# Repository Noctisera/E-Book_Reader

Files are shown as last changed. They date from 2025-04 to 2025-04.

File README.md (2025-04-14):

# OpenBook Reader

## 📘 Introduction  
**OpenBook Reader** is an open-source hardware project focused on delivering a practical, low-cost e-book device. Its primary aim is to build the physical design assets—such as schematics, board layouts, and casing models—needed for manufacturing the device according to system-level specs.

This initiative includes:
- Circuit design and layout.
- PCB preparation for fabrication.
- CAD models for enclosure and hardware integration.

---

## 🔧 Project Contents

This repository contains everything needed to bring the device to life, from electronics to mechanical files. Key folders include:

- **Electronics Design**
  - Circuit schematics  
  - Board layout data  
- **Fabrication Files**
  - Manufacturing exports (e.g., Gerbers)  
  - Assembly references (e.g., BOM, placement files)  
- **CAD Assets**
  - Mechanical parts in 3D format (STEP, Fusion360)  
- **Miscellaneous**
  - Licensing information  
  - Documentation  

---

## 📦 Components Summary

### Block Diagram
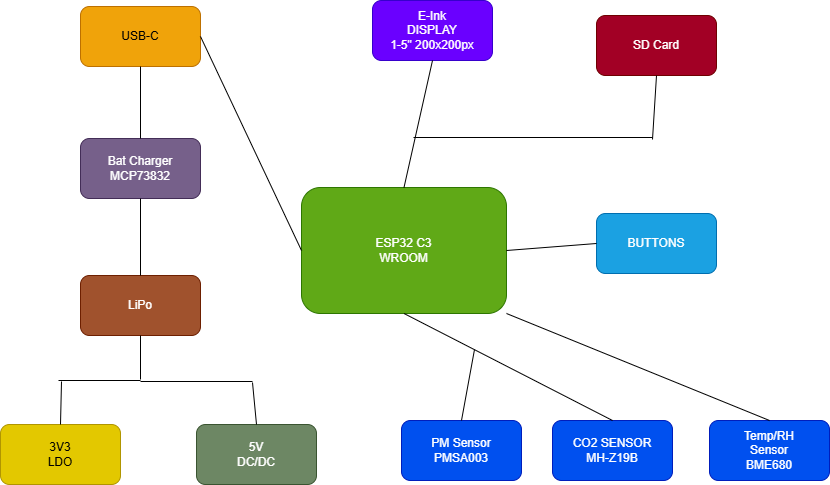
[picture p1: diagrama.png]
E-Book Reader Diagram


Below is a selection of the main components used in the hardware design. For each, you’ll find supplier and datasheet links for reference.

## Bill of Materials (BOM)

| Component | Link | Datasheet |
| :--- | :--- | :--- |
| ESP32-C6 WROOM-1-N8 | [SnapMagic](https://www.snapeda.com/parts/ESP32-C6-WROOM-1-N8/Espressif+Systems/view-part/?ref=eda) | [Datasheet](https://www.snapeda.com/parts/ESP32-C6-WROOM-1-N8/Espressif%20Systems/datasheet/) |
| ESP32C6 Varistor 1812 | [Mouser](https://ro.mouser.com/ProductDetail/EPCOS-TDK/B72520T0350K062?qs=dEfas%2FXlABIszF52uu7vrg%3D%3D) | [Datasheet](https://www.tdk-electronics.tdk.com/inf/75/db/CTVS_14/Surge_protection_series.pdf) |
| ESP32 WROVER 0805 Capacitor | [Mouser](https://ro.mouser.com/ProductDetail/KYOCERA-AVX/SD0805S020S1R0?qs=jCA%252BPfw4LHbpkAoSnwrdjw%3D%3D) | [Datasheet](https://ro.mouser.com/datasheet/2/40/schottky-3165252.pdf) |
| ESP32 WROVER BME680 Sensor | [SnapMagic](https://www.snapeda.com/parts/BME680/Bosch/view-part/?welcome=home) | [Datasheet](https://www.snapeda.com/parts/BME680/Bosch%20Sensortec/datasheet/) |
| ESP32 WROVER MCP73831 Power Management | [Mouser](https://eu.mouser.com/ProductDetail/Microchip-Technology/MCP73831T-2ACI-OT?qs=yUQqVecv4qvbBQBGbHx0Mw%3D%3D) | [Datasheet](https://eu.mouser.com/datasheet/2/268/MCP73831_Family_Data_Sheet_DS20001984H-3441711.pdf) |
| ESP32 WROVER P-Channel MOSFET | [Component Search Engine](https://componentsearchengine.com/part-view/DMG2305UX-7/Diodes%20Incorporated) | [Datasheet](https://www.diodes.com//assets/Datasheets/DMG2305UX.pdf) |
| LED Chip 0603 | [SnapMagic](https://www.snapeda.com/parts/KP-1608SURCK/Kingbright/view-part/?ref=search&t=LED%200603) | [Datasheet](https://www.snapeda.com/parts/KP-1608SURCK/Kingbright/datasheet/) |
| SJ | [GrabCad](https://grabcad.com/library/solder-jumpers-1) | [Datasheet](https://www.youtube.com/watch?v=dQw4w9WgXcQ) |
| LTSPICE Resistor 0402 | [Component Search Engine](https://componentsearchengine.com/part-view/R0402%201%25%20100%20K%20(RC0402FR-07100KL)/YAGEO) | [Datasheet](https://www.yageo.com/upload/media/product/products/datasheet/rchip/PYu-RC_Group_51_RoHS_L_12.pdf) |
| RCL CPOL 3528 | [SnapMagic](https://www.snapeda.com/parts/TAJB475K025RNJ/AVX/view-part/?ref=dk&t=capacitor%203528&con_ref=None) | [Datasheet](https://s3.amazonaws.com/snapeda/datasheet/TAJB475K025RNJ_AVX.pdf) |
| 112A-TAAR-R03 | [Comet](https://store.comet.srl.ro/Catalogue/Product/43497/) | [Datasheet](https://store.comet.bg/download-file.php?id=27596) |
| Capacitor 0402 | [Component Search Engine](https://componentsearchengine.com/part-view/CC0402MRX5R5BB106/YAGEO) | [Datasheet](https://componentsearchengine.com/Datasheets/2/CC0402MRX5R5BB106.pdf) |
| 744043680 IND | [Mouser](https://eu.mouser.com/ProductDetail/Wurth-Elektronik/744043680?qs=PGXP4M47uW6VkZq%252BkzjrHA%3D%3D) | [Datasheet](https://www.we-online.com/components/products/datasheet/744043680.pdf) |
| BD5229G-TR | [Component Search Engine](https://componentsearchengine.com/part-view/BD5229G-TR/ROHM%20Semiconductor) | [Datasheet](https://datasheet.datasheetarchive.com/originals/distributors/Datasheets_SAMA/f2b9741ef86007909f138d561a359946.pdf) |
| Custom Button | [Panasonic](https://industry.panasonic.com/global/en/products/control/switch/light-touch/number/evqpuj02k) | [Datasheet](https://industry.panasonic.com/global/en/downloads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) |
| CPH3225A | [SnapMagic](https://www.snapeda.com/parts/CPH3225A/Seiko+Instruments/view-part/?ref=eda) | [Datasheet](https://www.snapeda.com/parts/CPH3225A/Seiko%20Instruments/datasheet/) |
| DS3231SN RTC | [SnapMagic](https://www.snapeda.com/parts/DS3231SN%23/Analog+Devices/view-part/?ref=eda) | [Datasheet](https://www.snapeda.com/parts/DS3231SN%23/Analog%20Devices/datasheet/) |
| FH34SRJ-24S-0.5SH Connector | [Component Search Engine](https://componentsearchengine.com/part-view/FH34SRJ-24S-0.5SH(99)/Hirose) | [Datasheet](https://www.hirose.com/en/product/document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) |
| MAX17048G+T10 Battery Fuel Gauge | [SnapMagic](https://www.snapeda.com/parts/MAX17048G+T10/Analog+Devices/view-part/?ref=eda) | [Datasheet](https://www.snapeda.com/parts/MAX17048G+T10/Analog%20Devices/datasheet/) |
| MBR0530 Schottky Diode | [SnapMagic](https://www.snapeda.com/parts/MBR0530/Onsemi/view-part/?ref=eda) | [Datasheet](https://www.snapeda.com/parts/MBR0530/ON%20Semiconductor/datasheet/) |
| PGB1010603MR Inductor | [SnapMagic](https://www.snapeda.com/parts/PGB1010603MR/Littelfuse/view-part/?ref=eda) | [Datasheet](https://www.snapeda.com/parts/PGB1010603MR/Littelfuse%20Inc./datasheet/) |
| QWIIC Connector | [Mouser](https://eu.mouser.com/ProductDetail/Adafruit/4208?qs=PzGy0jfpSMtbScLbr0L5dw%3D%3D) | [Datasheet](https://www.youtube.com/watch?v=dQw4w9WgXcQ) |
| USB4110-GF-A USB Hub | [Component Search Engine](https://componentsearchengine.com/part-view/USB4110-GF-A/GCT%20(GLOBAL%20CONNECTOR%20TECHNOLOGY)) | [Datasheet](https://gct.co/files/drawings/usb4110.pdf) |
| SI1308EDL-T1-GE3 MOSFET | [SnapMagic](https://www.snapeda.com/parts/SI1308EDL-T1-GE3/Vishay+Siliconix/view-part/?ref=eda) | [Datasheet](https://www.youtube.com/watch?v=dQw4w9WgXcQ) |
| TPTP20R | [Comet](https://easyeda.com/component/7524403feb2642ac9f9f26dfb93ceacf) | [Datasheet](https://easyeda.com/component/7524403feb2642ac9f9f26dfb93ceacf) |
| USBLC6-2SC6Y USB Surge Protection | [SnapMagic](https://www.snapeda.com/parts/USBLC6-2SC6Y/STMicroelectronics/view-part/?ref=eda) | [Datasheet](https://www.snapeda.com/parts/USBLC6-2SC6Y/STMicroelectronics/datasheet/) |
| W25Q512JVEIQ Flash Memory | [SnapMagic](https://www.snapeda.com/parts/W25Q512JVEIQ/Winbond+Electronics/view-part/?ref=eda) | [Datasheet](https://www.snapeda.com/parts/W25Q512JVEIQ/Winbond%20Electronics/datasheet/) |
| XC6220A331MR-G Voltage Regulator | [Component Search Engine](https://componentsearchengine.com/part-view/XC6220A331MR-G/Torex) | [Datasheet](https://product.torexsemi.com/system/files/series/xc6220.pdf) |

---

## 🧠 Key Modules and Functionality

### 🟡 Power System  
- **Battery:** Rechargeable Li-Po providing 3.7V, 1800mAh capacity.  
- **Charger:** Manages safe charging through USB-C.  
- **Regulation:** LDOs provide clean power to different system sections.

### 🔲 Display Unit  
- **Type:** 7.5-inch e-paper screen (black & white).  
- **Comms:** SPI-based, ultra-low-power refresh.

### 🎛 Microcontroller  
- **Model:** ESP32-C6  
- **Role:** Central processor managing all I/O, display, memory, and sensors.  
- **Connectivity:** Offers Wi-Fi and Bluetooth for syncing or updates.

### 🌦 Environmental Sensor  
- **Chip:** BME688  
- **Function:** Captures environmental data (temp, pressure, humidity, gas).

### 🕒 Real-Time Clock  
- **RTC:** DS3231  
- **Use Case:** Keeps time even without power—great for tracking usage.

### 💾 Storage  
- **Flash Memory:** For storing firmware and runtime data.  
- **SD Card Support:** Optional external storage for large file handling (e.g. e-books).

### 🧩 Expandability  
- **Connectors:** I2C/SPI breakout headers support add-on modules.  
- **Test Points:** Available for programming, debugging, and diagnostics.

---

## 🔌 Interfaces & I/O

| Interface | Purpose |
|---|---|
| **SPI**  | Display, SD Card, Flash Memory |
| **I2C**  | Sensor, RTC |
| **USB-C**| Charging & data |
| **GPIO** | Button inputs, status indicators |

---

## 📃 License  
This project is released under the MIT License—feel free to use, remix, and contribute.

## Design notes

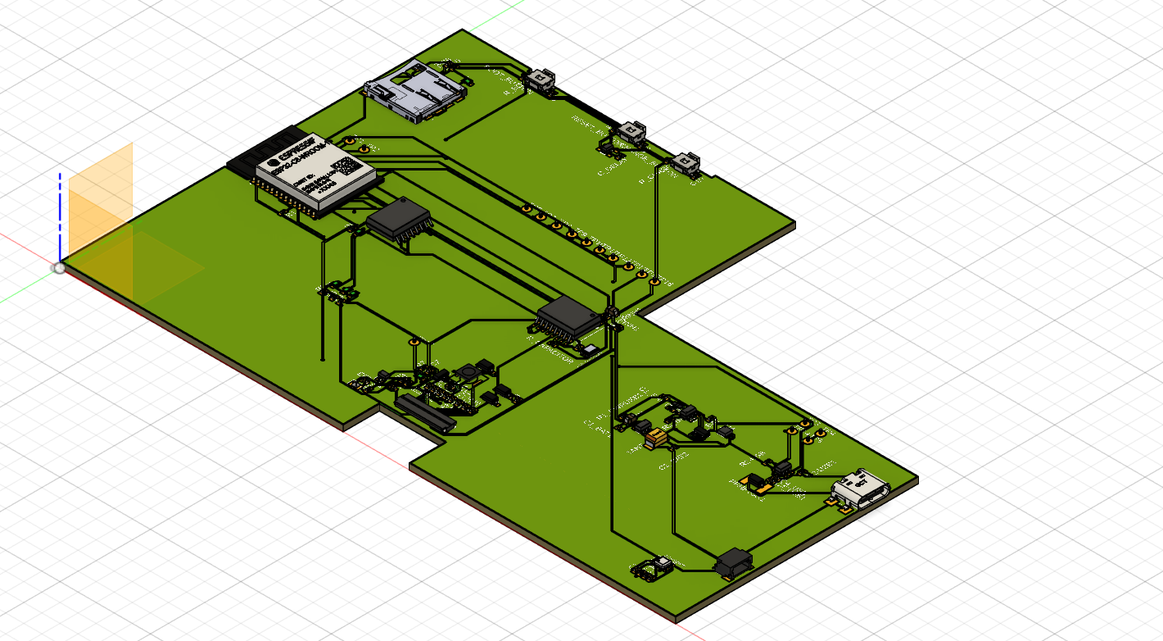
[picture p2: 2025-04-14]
Images/3D_PCB.png

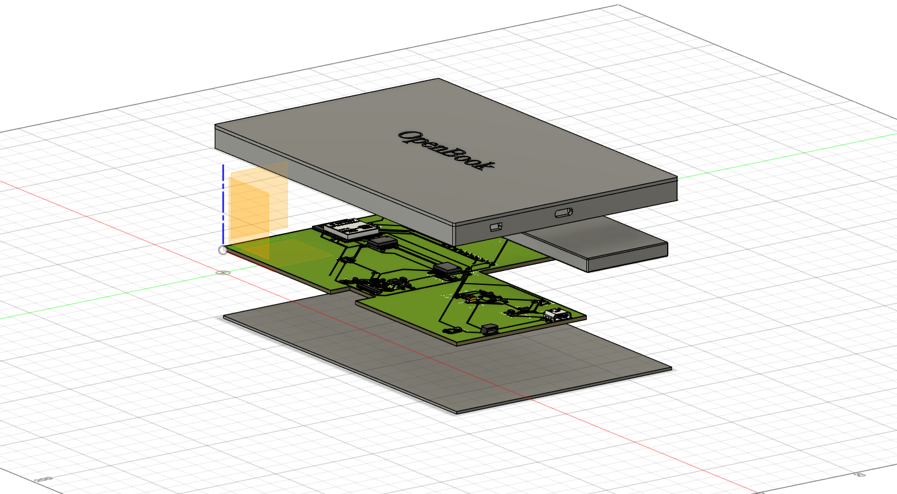
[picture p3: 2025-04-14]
Images/Layered View.png

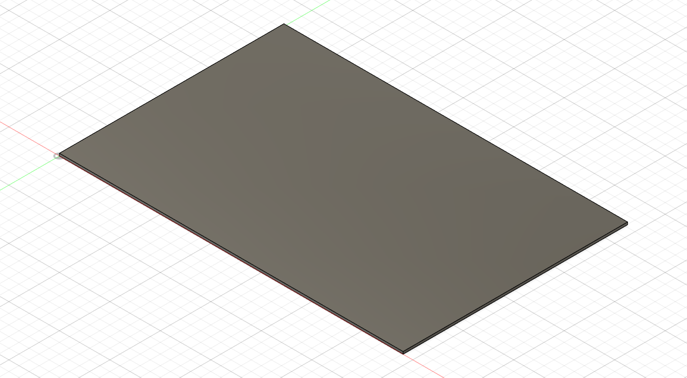
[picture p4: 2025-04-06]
Images/Display v1.png

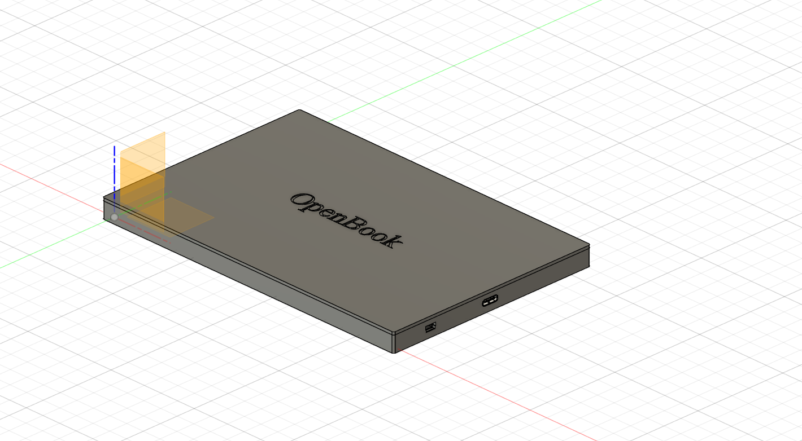
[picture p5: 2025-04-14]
Images/Whole E-Book.png

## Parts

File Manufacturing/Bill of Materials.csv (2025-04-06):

Qty | Value | Device | Package | Parts | Description | ARROW_PART_NUMBER | ARROW_PRICE-STOCK | AVAILABILITY | CENTROID_NOT_SPECIFIED | CHECK_PRICES | COPYRIGHT | DATASHEET | DESCRIPTION | DIGIKEY_DESCRIPTION | DIGIKEY_PART_NUMBER | HEIGHT | LEAD_FREE | MANUFACTURER_NAME | MANUFACTURER_PART_NUMBER | MF | MFR_NAME | MOUSER_PART_NUMBER | MOUSER_PRICE-STOCK | MOUSER_TESTING_PART_NUMBER | MOUSER_TESTING_PRICE-STOCK | MP | MPN | PACKAGE | POPULARITY | PREFIX | PRICE | PROD_ID | PURCHASE-URL | ROHS | SNAPEDA_LINK | SPICEMODEL | SPICEPREFIX | TEMPERATURE_RANGE_HIGH | TEMPERATURE_RANGE_LOW | TP_SIGNAL_NAME | VALUE
1 |  | ADAFRUIT_LEDCHIP-LED0603 | ADAFRUIT_CHIP-LED0603 | CHG_LED | LED
1 |  | SJ | SJ | SJ1 | SMD solder JUMPER |  |  |  |  |  |  |  |  |  |  |  |  |  |  |  |  |  |  |  |  |  |  |  | 3
1 | 0.47 | ESP32_WROVER_EAGLE-LTSPICE_RR0402 | ESP32_WROVER_EAGLE-LTSPICE_R0402 | R3 | RESISTOR, European symbol |  |  |  |  |  |  |  |  |  |  |  |  |  |  |  |  |  |  |  |  |  |  |  |  |  |  |  |  |  |  | NONE | R
1 | 100K | ESP32_WROVER_EAGLE-LTSPICE_RR0402 | ESP32_WROVER_EAGLE-LTSPICE_R0402 | R1_PWRUSB1 | RESISTOR, European symbol |  |  |  |  |  |  |  |  |  |  |  |  |  |  |  |  |  |  |  |  |  |  |  |  |  |  |  |  |  |  | NONE | R
8 | 100nF | EAGLE-LTSPICE_CC0402 | EAGLE-LTSPICE_C0402 | C1, C2, C4_USB1, C6, C8, C9, C10, C_DELAY | CAPACITOR, European symbol |  |  |  |  |  |  |  |  |  |  |  |  |  |  |  |  |  |  |  |  |  |  |  |  |  |  |  |  |  |  | NONE | C
1 | 100uF | RCL_CPOL-EUCT3528 | RCL_CT3528 | TANT | POLARIZED CAPACITOR, European symbol |  |  |  |  |  |  |  |  |  |  |  |  |  |  |  |  |  |  |  |  |  |  |  | 0 |  |  |  |  |  |  |  | C
17 | 10K | ESP32_WROVER_EAGLE-LTSPICE_RR0402 | ESP32_WROVER_EAGLE-LTSPICE_R0402 | R1, R1_PINH, R1_PINH1, R2-USB1, R2_PINH, R2_PINH1, R4, R5, R6, R7, R8, R9, R10, R_BOOT, R_CHANGE, R_CL1, R_RESET | RESISTOR, European symbol |  |  |  |  |  |  |  |  |  |  |  |  |  |  |  |  |  |  |  |  |  |  |  |  |  |  |  |  |  |  | NONE | R
1 | 10uF | EAGLE-LTSPICE_CC0402 | EAGLE-LTSPICE_C0402 | C7 | CAPACITOR, European symbol |  |  |  |  |  |  |  |  |  |  |  |  |  |  |  |  |  |  |  |  |  |  |  |  |  |  |  |  |  |  | NONE | C
1 | 112A-TAAR-R03_ATTEND | 112A-TAAR-R03_ATTEND | 112ATAARR03ATTEND | J4 | Micro SD Card Socket, Push-Push Type, Top Mount, SMT, H=1.83mm, 10u |  |  |  |  |  |  |  | Micro SD Card Socket | Push-Push Type | Top Mount | SMT | H=1.83mm | 10u |  |  | 1.9mm |  | ATTEND | 112A-TAAR-R03 ATTEND
1 | 15 | ESP32_WROVER_EAGLE-LTSPICE_RR0402 | ESP32_WROVER_EAGLE-LTSPICE_R0402 | R_CAPACITOR | RESISTOR, European symbol |  |  |  |  |  |  |  |  |  |  |  |  |  |  |  |  |  |  |  |  |  |  |  |  |  |  |  |  |  |  | NONE | R
1 | 1uF | EAGLE-LTSPICE_CC0402 | EAGLE-LTSPICE_C0402 | C5 | CAPACITOR, European symbol |  |  |  |  |  |  |  |  |  |  |  |  |  |  |  |  |  |  |  |  |  |  |  |  |  |  |  |  |  |  | NONE | C
10 | 1uF/50V | EAGLE-LTSPICE_CC0402 | EAGLE-LTSPICE_C0402 | EFD_C1, EFD_C2, EFD_C5, EFD_C6, EFD_C7, EPD_C8, EPD_C9, EPD_C10, EPD_C11, EPD_C12 | CAPACITOR, European symbol |  |  |  |  |  |  |  |  |  |  |  |  |  |  |  |  |  |  |  |  |  |  |  |  |  |  |  |  |  |  | NONE | C
1 | 2.2 | ESP32_WROVER_EAGLE-LTSPICE_RR0402 | ESP32_WROVER_EAGLE-LTSPICE_R0402 | R2 | RESISTOR, European symbol |  |  |  |  |  |  |  |  |  |  |  |  |  |  |  |  |  |  |  |  |  |  |  |  |  |  |  |  |  |  | NONE | R
1 | 200 | ESP32_WROVER_EAGLE-LTSPICE_RR0402 | ESP32_WROVER_EAGLE-LTSPICE_R0402 | R1_BAT | RESISTOR, European symbol |  |  |  |  |  |  |  |  |  |  |  |  |  |  |  |  |  |  |  |  |  |  |  |  |  |  |  |  |  |  | NONE | R
2 | 20V/4.2A/52m?/1.4W | ESP32_WROVER_SPARKFUN-DISCRETESEMI_MOSFET_PCH-DMG2305UX-7 | ESP32_WROVER_SPARKFUN-DISCRETESEMI_SOT23-3 | Q1, Q2 | P-channel MOSFETs |  |  |  |  |  |  |  |  |  |  |  |  |  |  |  |  |  |  |  |  |  |  |  |  |  |  | TRAN-14388 |  |  |  |  |  |  |  |  | 20V/4.2A/52m?/1.4W
1 | 2K | ESP32_WROVER_EAGLE-LTSPICE_RR0402 | ESP32_WROVER_EAGLE-LTSPICE_R0402 | R2_BAT | RESISTOR, European symbol |  |  |  |  |  |  |  |  |  |  |  |  |  |  |  |  |  |  |  |  |  |  |  |  |  |  |  |  |  |  | NONE | R
5 | 4.7uF | EAGLE-LTSPICE_CC0402 | EAGLE-LTSPICE_C0402 | C1_BAT, C1_BAT1, C1_BAT2, C2_BAT, C4_USB | CAPACITOR, European symbol |  |  |  |  |  |  |  |  |  |  |  |  |  |  |  |  |  |  |  |  |  |  |  |  |  |  |  |  |  |  | NONE | C
1 | 4.7uF/25V | EAGLE-LTSPICE_CC0402 | EAGLE-LTSPICE_C0402 | C4 | CAPACITOR, European symbol |  |  |  |  |  |  |  |  |  |  |  |  |  |  |  |  |  |  |  |  |  |  |  |  |  |  |  |  |  |  | NONE | C
1 | 5k1 | ESP32_WROVER_EAGLE-LTSPICE_RR0402 | ESP32_WROVER_EAGLE-LTSPICE_R0402 | R2-USB | RESISTOR, European symbol |  |  |  |  |  |  |  |  |  |  |  |  |  |  |  |  |  |  |  |  |  |  |  |  |  |  |  |  |  |  | NONE | R
1 | 744043680IND_4828-WE-TPC_WRE | 744043680IND_4828-WE-TPC_WRE | IND_4828-WE-TPC_WRE | L1 |  |  |  |  |  |  | Copyright (C) 2024 Ultra Librarian. All rights reserved. |  |  |  |  |  |  |  | 744043680 |  | Wurth Electronics
1 | BD5229G-TR | BD5229G-TR | SOT95P280X125-5N | IC1 | Voltage Detector with Adjustable Delay Time: CMOS processes are utilized to develop high precision, low current consumption CMOS reset ICs that allow arbitrary setting of the delay time. The extensive lineup includes both Nch Open Drain and CMOS output types in a wide range of detection voltages (from 2.3V to 6.0V, in 0.1V steps), enabling selection of the ideal solution based on customer requirements. In addition, the entire series is of course both lead-free and RoHS-compliant. |  |  |  |  |  |  |  | Voltage Detector with Adjustable Delay Time: CMOS processes are utilized to develop high precision | low current consumption CMOS reset ICs that allow arbitrary setting of the delay time. The extensive lineup includes both Nch Open Drain and CMOS output types in a wide range of detection voltages (from 2.3V to 6.0V | in 0.1V steps) | enabling selection of the ideal solution based on customer requirements. In addition | the entire series is of course both lead-free and RoHS-compliant. |  |  | 1.25mm |  | ROHM Semiconductor | BD5229G-TR |  |  | 755-BD5229G-TR | https://www.mouser.co.uk/ProductDetail/ROHM-Semiconductor/BD5229G-TR?qs=4kLU8WoGk0vvnhrrYwdszw%3D%3D
3 | BUTTON_CUSYOMV1 | BUTTON_CUSYOMV1 | MYBUTTON | BOOT_BUTTON, CHANGE_BUTTON, RESET_BUTTON
1 | CPH3225A | CPH3225A | CAPCP3225X100N | C10_SUPERCAP | Cap 0.011F 3.3V 1210 Flat Check availability |  |  | Not in stock |  | https://www.snapeda.com/parts/CPH3225A/Seiko+Instruments/view-part/?ref=eda |  |  | 11 mF (EDLC) Supercapacitor 3.3 V 1210 (3225 Metric) - - |  |  |  |  |  |  | Seiko Instruments |  |  |  |  |  | CPH3225A |  | 1210 Seiko |  |  | None |  | https://www.snapeda.com/api/url_track_click_mouser/?unipart_id=562593&manufacturer=Seiko Instruments&part_name=CPH3225A&search_term=None |  | https://www.snapeda.com/parts/CPH3225A/Seiko+Instruments/view-part/?ref=snap
1 | DS3231SN# | DS3231SN# | SOIC127P1032X265-16N | U3 | Real Time Clock Serial 16-Pin SOIC W T/R Check availability |  |  | In Stock |  | https://www.snapeda.com/parts/DS3231SN%23/Analog+Devices/view-part/?ref=eda |  |  | Extremely Accurate I2C-Integrated RTC/TCXO/Crystal |  |  |  |  |  |  | Analog Devices |  |  |  |  |  | DS3231SN# |  | SOIC-16 Maxim |  |  | None |  | https://www.snapeda.com/api/url_track_click_mouser/?unipart_id=99048&manufacturer=Analog Devices&part_name=DS3231SN#&search_term=None |  | https://www.snapeda.com/parts/DS3231SN%23/Analog+Devices/view-part/?ref=snap
1 | ESP32-C6-WROOM-1-N8 | ESP32-C6-WROOM-1-N8 | XCVR_ESP32-C6-WROOM-1-N8 | U2 | Check availability |  |  | In Stock |  | https://www.snapeda.com/parts/ESP32-C6-WROOM-1-N8/Espressif+Systems/view-part/?ref=eda |  |  | Multiprotocol Modules ESP32-C6 module | Wi-Fi 6 in 2.4 GHz band | Bluetooth 5 | Zigbee 3.0 and Thread. ESP34-WROOM Compatible - ENGINEERING SAMPLE |  |  |  |  |  |  | Espressif Systems |  |  |  |  |  | ESP32-C6-WROOM-1-N8 |  | None |  |  | None |  |  |  | https://www.snapeda.com/parts/ESP32-C6-WROOM-1-N8/Espressif+Systems/view-part/?ref=snap
1 | ESP32C6_VARISTORCN1812 | ESP32C6_VARISTORCN1812 | ESP32C6_VARISTOR_CT/CN1812 | PFMF.050.1 | VARISTOR |  |  |  |  |  |  |  |  |  |  |  |  |  |  |  |  |  |  |  |  |  |  |  | 0
2 | ESP32_WROVER_AVX---SD0805S020S1R0_AVX_SD0805S020S1R0_0_0AVX_SD0805S020S1R0_0_0 | ESP32_WROVER_AVX---SD0805S020S1R0_AVX_SD0805S020S1R0_0_0AVX_SD0805S020S1R0_0_0 | ESP32_WROVER_AVX---SD0805S020S1R0_AVX_SD0805S020S1R0_0 | D2, D7 | Schottky Barrier Rectifier Diode |  |  |  | No |  |  | http://datasheets.avx.com/schottky.pdf |  | DIODE SCHOTTKY 20V 1A 0805 | 478-7800-1-ND |  | yes |  |  | AVX |  | 581-SD0805S020S1R0 |  |  |  |  |  | 0805 (2012 metric) |  | D |  |  |  | yes |  |  |  | +125°C | -55°C
1 | ESP32_WROVER_BME680_BME680 | ESP32_WROVER_BME680_BME680 | ESP32_WROVER_BME680_PSON80P300X300X100-8N | SENSOR2 | Integrated Environmental Unit |  |  | Unavailable |  |  |  |  | Integrated Environmental Unit |  |  |  |  |  |  | Bosch Sensortec |  |  |  |  |  | BME680 |  | LGA-8 Bosch Tools |  |  | None
1 | ESP32_WROVER_SPARKFUN-IC-POWER_MCP73831 | ESP32_WROVER_SPARKFUN-IC-POWER_MCP73831 | ESP32_WROVER_SPARKFUN-IC-POWER_SOT23-5 | MCP73831 | MCP73831T Li-Ion, Li-Pol Controller |  |  |  |  |  |  |  |  |  |  |  |  |  |  |  |  |  |  |  |  |  |  |  |  |  |  | IC-09995
1 | FH34SRJ-24S-0.5SH_99_ | FH34SRJ-24S-0.5SH_99_ | FH34SRJ24S05SH99 | J1 | (0.50mm) Surface Mount, Right Angle |  |  |  |  |  |  |  | 24 Position FFC | FPC Connector Contacts | (0.50mm) Surface Mount | Right Angle |  |  | 1.1mm |  | Hirose | FH34SRJ-24S-0.5SH(99) |  |  | 798-FH34SRJ24S05SH99 | https://www.mouser.co.uk/ProductDetail/Hirose-Connector/FH34SRJ-24S-0.5SH99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
1 | MAX17048G+T10 | MAX17048G+T10 | SON50P200X200X80-9N | U4 | Check availability |  |  | In Stock |  | https://www.snapeda.com/parts/MAX17048G+T10/Analog+Devices/view-part/?ref=eda |  |  | 3µA 1-Cell/2-Cell Fuel Gauge with ModelGauge |  |  |  |  |  |  | Analog Devices |  |  |  |  |  | MAX17048G+T10 |  | TDFN-8 Maxim |  |  | None |  | https://www.snapeda.com/api/url_track_click_mouser/?unipart_id=329239&manufacturer=Analog Devices&part_name=MAX17048G+T10&search_term=None |  | https://www.snapeda.com/parts/MAX17048G+T10/Analog+Devices/view-part/?ref=snap
3 | MBR0530 | MBR0530 | SOD3716X135N | D3, D4, D5 | ON SEMICONDUCTOR - MBR0530 - DIODE, SCHOTTKY, 0.5A, 30V, SOD-123 |  |  | In Stock |  | https://www.snapeda.com/parts/MBR0530/Onsemi/view-part/?ref=eda |  |  | Diode Schottky 30 V 500mA Surface Mount SOD-123 |  |  |  |  |  |  | ON Semiconductor |  |  |  |  |  | MBR0530 |  | SOD-123-2 ON Semiconductor |  |  | None |  | https://www.snapeda.com/api/url_track_click_mouser/?unipart_id=179458&manufacturer=ON Semiconductor&part_name=MBR0530&search_term=None |  | https://www.snapeda.com/parts/MBR0530/Onsemi/view-part/?ref=snap
6 | PGB1010603MR | PGB1010603MR | DIOC1608X36N | D6, D8, D9, D10, D11, D12 | Check availability |  |  | In Stock |  | https://www.snapeda.com/parts/PGB1010603MR/Littelfuse/view-part/?ref=eda |  |  | 150V (Typ) Clamp - Ipp Tvs Diode Surface Mount 0603 (1608 Metric) |  |  |  |  |  |  | Littelfuse Inc. |  |  |  |  |  | PGB1010603MR |  | 0603 Littelfuse Inc. |  |  | None |  | https://www.snapeda.com/api/url_track_click_mouser/?unipart_id=5659453&manufacturer=Littelfuse Inc.&part_name=PGB1010603MR&search_term=None |  | https://www.snapeda.com/parts/PGB1010603MR/Littelfuse/view-part/?ref=snap
1 | QWIIC_RIGHT_ANGLE | QWIIC_CONNECTORJS-1MM | JST04_1MM_RA | J3 | SparkFun I2C Standard Qwiic Connector |  |  |  |  |  |  |  |  |  |  |  |  |  |  |  |  |  |  |  |  |  |  |  |  |  |  | CONN-13694 |  |  |  |  |  |  |  |  | QWIIC_RIGHT_ANGLE
1 | SAMACSYS_PARTS_USB4110-GF-A | SAMACSYS_PARTS_USB4110-GF-A | SAMACSYS_PARTS_USB4110GFA | J2 | CONN USB 2.0 TYPE-C R/A SMT |  |  |  |  |  |  |  | CONN USB 2.0 TYPE-C R/A SMT |  |  | 3.26mm |  | GCT (GLOBAL CONNECTOR TECHNOLOGY) | USB4110-GF-A |  |  | 640-USB4110-GF-A | https://www.mouser.co.uk/ProductDetail/GCT/USB4110-GF-A?qs=KUoIvG%2F9IlYiZvIXQjyJeA%3D%3D
1 | SI1308EDL-T1-GE3 | SI1308EDL-T1-GE3 | SOT65P210X110-3N | Q3 | MOSFET N-Ch 30V 1.5A TrenchFET SC70 Vishay Si1308EDL-T1-GE3 N-channel MOSFET Transistor, 1.5 A, 30 V, 3-Pin SC-70 |  |  | In Stock |  | https://www.snapeda.com/parts/SI1308EDL-T1-GE3/Vishay+Siliconix/view-part/?ref=eda |  |  | Si1308EDL-T1-GE3 N-channel MOSFET Transistor | 1.5 A | 30 V | 3-Pin SC-70 | Siliconix / Vishay SI1308EDL-T1-GE3 |  |  |  |  |  |  | Vishay Siliconix |  |  |  |  |  | SI1308EDL-T1-GE3 |  | SOT-323 Vishay Semiconductor |  |  | None |  | https://www.snapeda.com/api/url_track_click_mouser/?unipart_id=274603&manufacturer=Vishay Siliconix&part_name=SI1308EDL-T1-GE3&search_term=None |  | https://www.snapeda.com/parts/SI1308EDL-T1-GE3/Vishay+Siliconix/view-part/?ref=snap
17 | TPTP20R | TPTP20R | TP20R | TP1, TP2, TP3, TP4, TP5, TP6, TP7, TP8, TP9, TP10, TP11, TP12, TP13, TP14, TP15, TP16, TP17 | Test pad |  |  |  |  |  |  |  |  |  |  |  |  |  |  |  |  |  |  |  |  |  |  |  | 2
1 | USBLC6-2SC6Y | USBLC6-2SC6Y | SOT95P280X145-6N | D1 | Low Cap. ESD Protection Auto SOT-23-6 STMicroelectronics USBLC6-2SC6Y, Dual Uni-Directional TVS Diode Array, 6-Pin SOT-23 |  |  | In Stock |  | https://www.snapeda.com/parts/USBLC6-2SC6Y/STMicroelectronics/view-part/?ref=eda |  |  | 17V Clamp 5A (8/20µs) Ipp Tvs Diode Surface Mount SOT-23-6 |  |  |  |  |  |  | STMicroelectronics |  |  |  |  |  | USBLC6-2SC6Y |  | SOT-23-6 STMicroelectronics |  |  | None |  |  |  | https://www.snapeda.com/parts/USBLC6-2SC6Y/STMicroelectronics/view-part/?ref=snap
1 | W25Q512JVEIQ | W25Q512JVEIQ | SON127P600X800X80-9N | U1 | Check availability |  |  | In Stock |  | https://www.snapeda.com/parts/W25Q512JVEIQ/Winbond+Electronics/view-part/?ref=eda |  |  | FLASH - NOR Memory IC 512Mb (64M x 8) SPI - Quad I/O 133 MHz 8-WSON (8x6) |  |  |  |  |  |  | Winbond Electronics |  |  |  |  |  | W25Q512JVEIQ |  | Package |  |  | None |  |  |  | https://www.snapeda.com/parts/W25Q512JVEIQ/Winbond+Electronics/view-part/?ref=snap
1 | XC6220A331MR-G | XC6220A331MR-G | SOT95P280X120-5N | IC4 | LDO Voltage Regulators |  |  |  |  |  |  |  | LDO Voltage Regulators |  |  | 1.2mm |  | Torex | XC6220A331MR-G |  |  | 865-XC6220A331MR-G | https://www.mouser.co.uk/ProductDetail/Torex-Semiconductor/XC6220A331MR-G?qs=AsjdqWjXhJ8ZSWznL1J0gg%3D%3D

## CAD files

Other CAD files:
Mechanical/Exploded_View.step

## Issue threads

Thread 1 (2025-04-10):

ISSUE 1

Mirceacodeaza, 2025-04-10:
Sunt cateva componente in schematic carora le lipseste valoarea.

Noctisera, 2025-04-14:
Added missing values

Closed 2025-04-14.

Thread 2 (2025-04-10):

ISSUE 2

Mirceacodeaza, 2025-04-10:
Sunt foarte multe vias-uri( peste 100) in PCB.

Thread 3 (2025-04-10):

ISSUE 3

Mirceacodeaza, 2025-04-10:
Au mai ramas cateva erori la componentele care au fost date intentionat gresit in PCB.

Noctisera, 2025-04-14:
Solved the value issues

Closed 2025-04-14.

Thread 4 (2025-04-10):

ISSUE 4

Mirceacodeaza, 2025-04-10:
Exista doua componente(112ATAAR-R03ATTEND si JS-1MM QWIIC_CONNECTOR) care nu au modelul corect de port.

Noctisera, 2025-04-14:
Added 3D models to them.

Closed 2025-04-14.

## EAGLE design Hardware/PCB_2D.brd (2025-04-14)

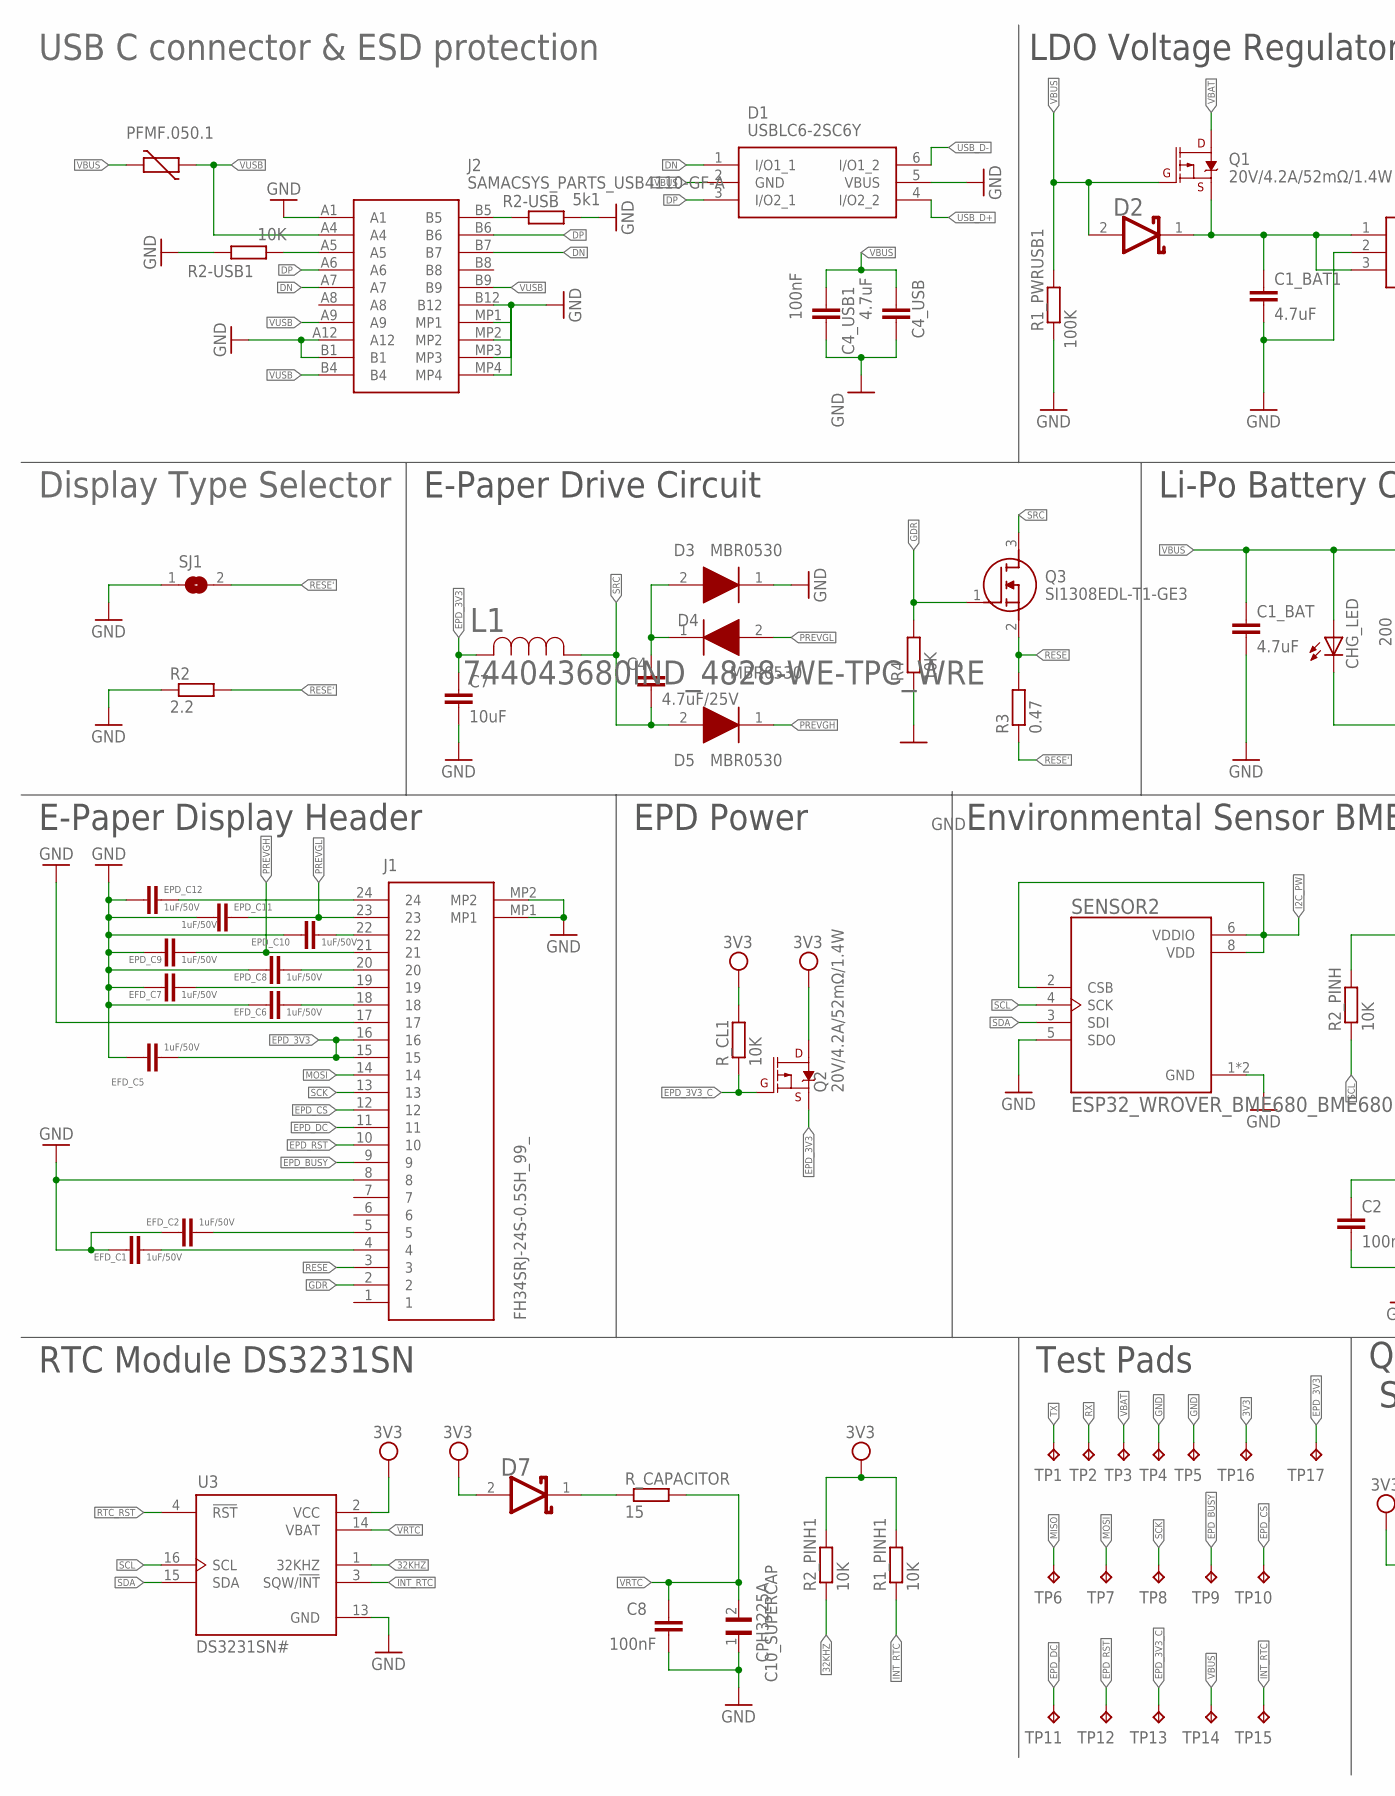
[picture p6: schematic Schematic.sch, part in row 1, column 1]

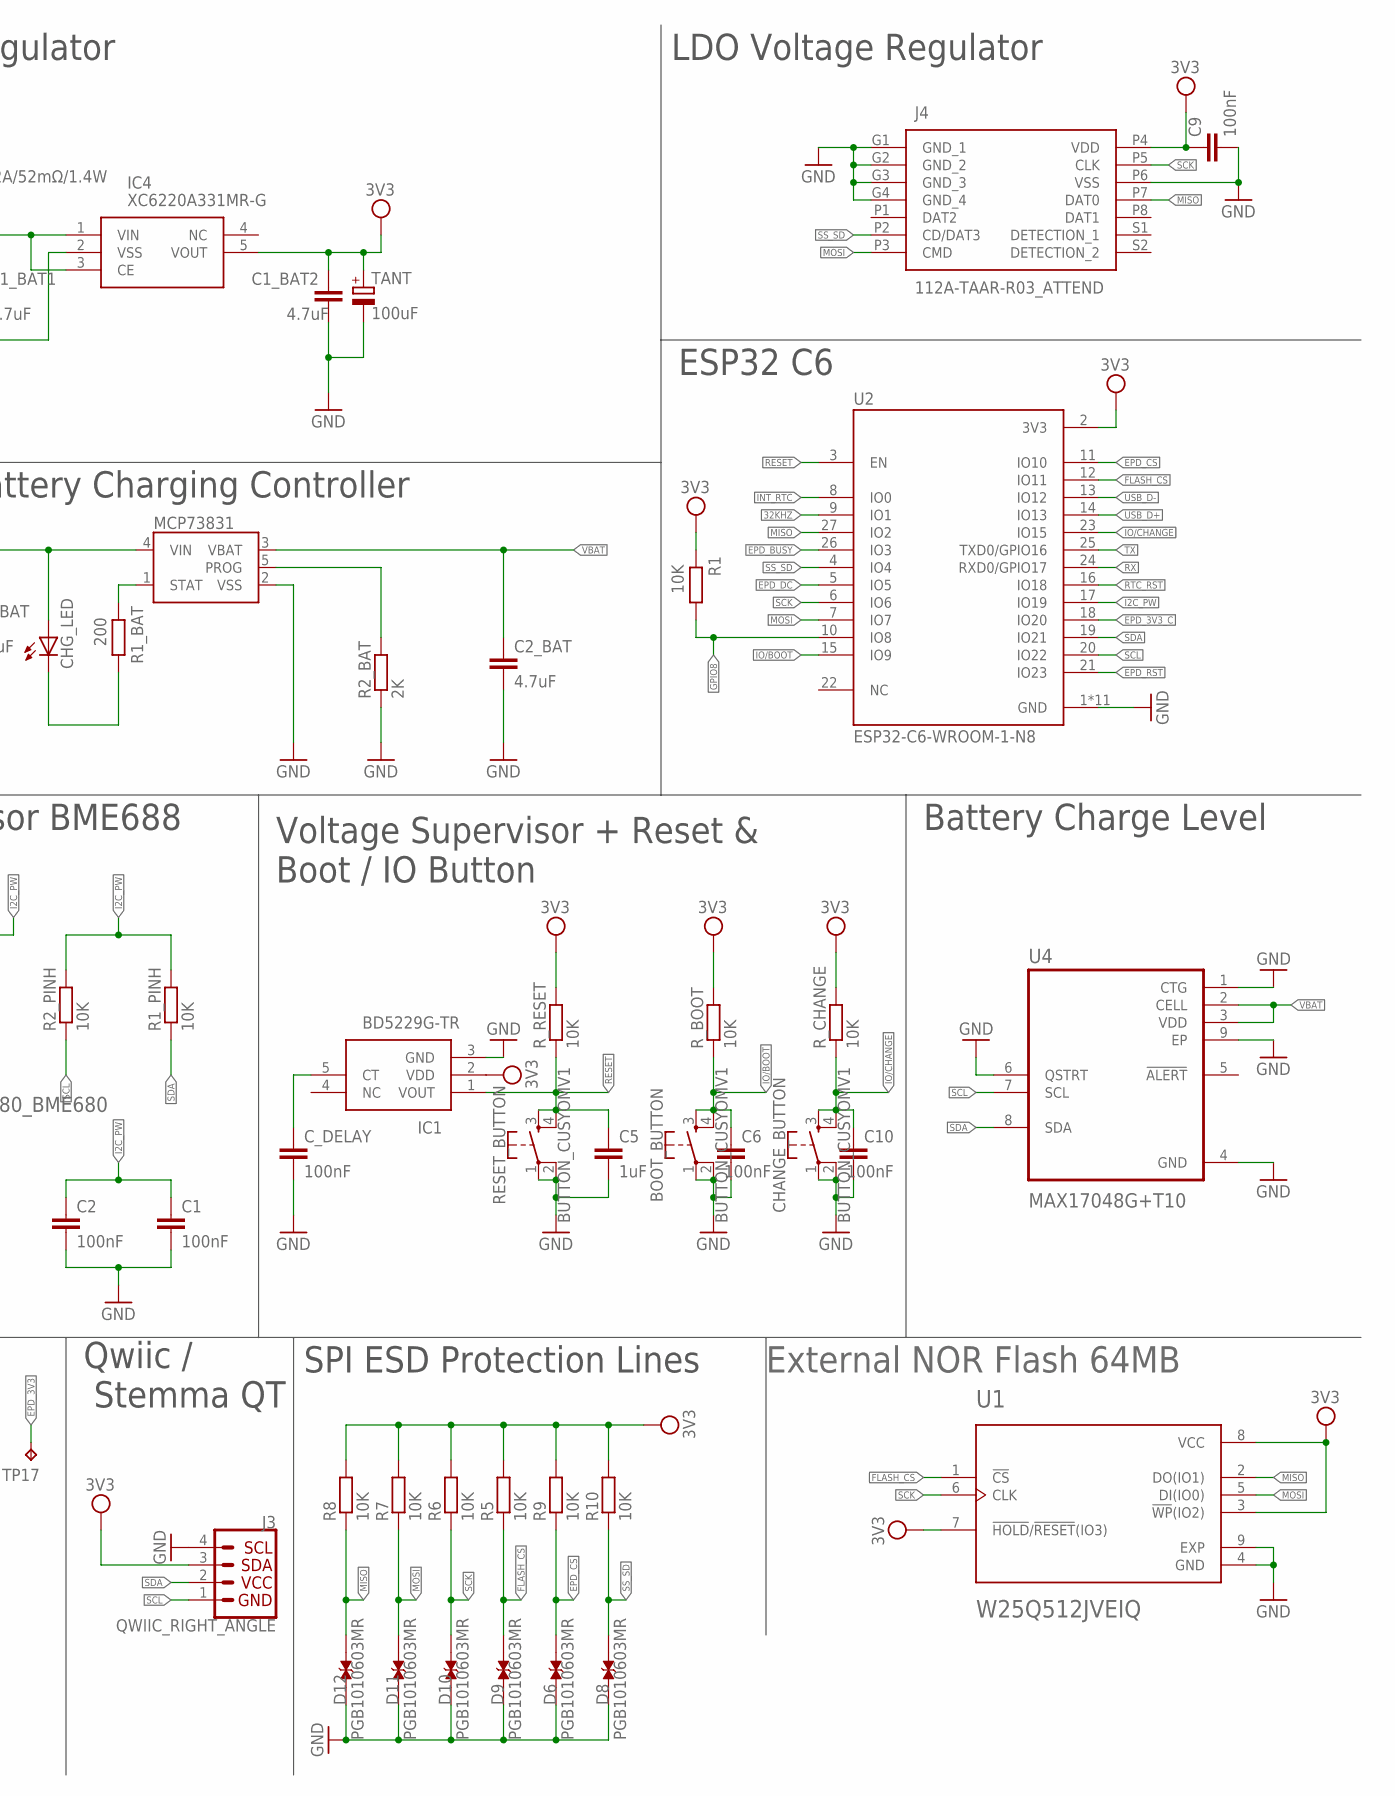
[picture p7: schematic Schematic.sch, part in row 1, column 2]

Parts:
BOOT_BUTTON: BUTTON_CUSYOMV1; MYBUTTON
C1, C2, C4_USB1, C6, C8, C9, C10: 100nF; EAGLE-LTSPICE_C0402
C1_BAT, C1_BAT1, C1_BAT2, C2_BAT, C4_USB: 4.7uF; EAGLE-LTSPICE_C0402
C4: 4.7uF/25V; EAGLE-LTSPICE_C0402
C5: 1uF; EAGLE-LTSPICE_C0402
C7: 10uF; EAGLE-LTSPICE_C0402
C10_SUPERCAP: CPH3225A; CAPCP3225X100N
CHANGE_BUTTON: BUTTON_CUSYOMV1; MYBUTTON
CHG_LED: ADAFRUIT_CHIP-LED0603
C_DELAY: 100nF; EAGLE-LTSPICE_C0402
D1: USBLC6-2SC6Y; SOT95P280X145-6N
D2, D7: ESP32_WROVER_AVX---SD0805S020S1R0_AVX_SD0805S020S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; ESP32_WROVER_AVX---SD0805S020S1R0_AVX_SD0805S020S1R0_0
D3, D4, D5: MBR0530; SOD3716X135N
D6, D8, D9, D10, D11, D12: PGB1010603MR; DIOC1608X36N
EFD_C1, EFD_C2, EFD_C5, EFD_C6, EFD_C7: 1uF/50V; EAGLE-LTSPICE_C0402
EPD_C8, EPD_C9, EPD_C10, EPD_C11, EPD_C12: 1uF/50V; EAGLE-LTSPICE_C0402
IC1: BD5229G-TR; SOT95P280X125-5N
IC4: XC6220A331MR-G; SOT95P280X120-5N
J1: FH34SRJ-24S-0.5SH_99_; FH34SRJ24S05SH99
J2: SAMACSYS_PARTS_USB4110-GF-A; SAMACSYS_PARTS_USB4110GFA
J3: QWIIC_RIGHT_ANGLE; JST04_1MM_RA
J4: 112A-TAAR-R03_ATTEND; 112ATAARR03ATTEND
L1: 744043680IND_4828-WE-TPC_WRE; IND_4828-WE-TPC_WRE
MCP73831: ESP32_WROVER_SPARKFUN-IC-POWER_MCP73831; ESP32_WROVER_SPARKFUN-IC-POWER_SOT23-5
PFMF.050.1: ESP32C6_VARISTORCN1812; ESP32C6_VARISTOR_CT/CN1812
Q1, Q2: 20V/4.2A/52mΩ/1.4W; ESP32_WROVER_SPARKFUN-DISCRETESEMI_SOT23-3
Q3: SI1308EDL-T1-GE3; SOT65P210X110-3N
R1, R1_PINH, R1_PINH1, R2-USB1, R2_PINH, R2_PINH1, R4, R5, R6, R7, R8, R9, R10: 10K; ESP32_WROVER_EAGLE-LTSPICE_R0402
R1_BAT: 200; ESP32_WROVER_EAGLE-LTSPICE_R0402
R1_PWRUSB1: 100K; ESP32_WROVER_EAGLE-LTSPICE_R0402
R2: 2.2; ESP32_WROVER_EAGLE-LTSPICE_R0402
R2-USB: 5k1; ESP32_WROVER_EAGLE-LTSPICE_R0402
R2_BAT: 2K; ESP32_WROVER_EAGLE-LTSPICE_R0402
R3: 0.47; ESP32_WROVER_EAGLE-LTSPICE_R0402
RESET_BUTTON: BUTTON_CUSYOMV1; MYBUTTON
R_BOOT: 10K; ESP32_WROVER_EAGLE-LTSPICE_R0402
R_CAPACITOR: 15; ESP32_WROVER_EAGLE-LTSPICE_R0402
R_CHANGE: 10K; ESP32_WROVER_EAGLE-LTSPICE_R0402
R_CL1: 10K; ESP32_WROVER_EAGLE-LTSPICE_R0402
R_RESET: 10K; ESP32_WROVER_EAGLE-LTSPICE_R0402
SENSOR2: ESP32_WROVER_BME680_BME680; ESP32_WROVER_BME680_PSON80P300X300X100-8N
SJ1: SJ
TANT: 100uF; RCL_CT3528
TP1, TP2, TP3, TP4, TP5, TP6, TP7, TP8, TP9, TP10, TP11, TP12, TP13, TP14, TP15, TP16, TP17: TPTP20R; TP20R
U1: W25Q512JVEIQ; SON127P600X800X80-9N
U2: ESP32-C6-WROOM-1-N8; XCVR_ESP32-C6-WROOM-1-N8
U3: DS3231SN#; SOIC127P1032X265-16N
U4: MAX17048G+T10; SON50P200X200X80-9N

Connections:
3V3: C1_BAT2.1, C9.1, D7.2 (ANODE), IC1.2 (VDD), IC4.5 (VOUT), J3.3, J4.P4 (VDD), Q2.3 (D), R1.2, R1_PINH1.2, R2_PINH1.2, R5.2, R6.2, R7.2, R8.2, R9.2, R10.2, R_BOOT.2, R_CHANGE.2, R_CL1.2, R_RESET.2, TANT.+, TP16.TP, U1.3 (!WP!(IO2)), U1.7 (!HOLD!/!RESET!(IO3)), U1.8 (VCC), U2.2 (3V3), U3.2 (VCC)
32KHZ: R2_PINH1.1, U2.9 (IO1), U3.1 (32KHZ)
DN: D1.1 (I/O1_1), J2.A7, J2.B7
DP: D1.3 (I/O2_1), J2.A6, J2.B6
EPD_3V3: C7.1, EFD_C5.1, J1.15, J1.16, L1.2, Q2.2 (S), TP17.TP
EPD_3V3_C: Q2.1 (G), R_CL1.1, TP13.TP, U2.18 (IO20)
EPD_BUSY: J1.9, TP9.TP, U2.26 (IO3)
EPD_CS: D6.2, J1.12, R9.1, TP10.TP, U2.11 (IO10)
EPD_DC: J1.11, TP11.TP, U2.5 (IO5)
EPD_RST: J1.10, TP12.TP, U2.21 (IO23)
FLASH_CS: D9.2, R5.1, U1.1 (!CS), U2.12 (IO11)
GDR: J1.2, Q3.1 (G), R4.2
GND: BOOT_BUTTON.1, BOOT_BUTTON.2, C1.2, C1_BAT.2, C1_BAT1.2, C1_BAT2.2, C2.2, C2_BAT.2, C4_USB.2, C4_USB1.2, C5.2, C6.2, C7.2, C8.2, C9.2, C10.2, C10_SUPERCAP.1, CHANGE_BUTTON.1, CHANGE_BUTTON.2, C_DELAY.2, D1.5 (VBUS), D3.1 (K), D6.1, D8.1, D9.1, D10.1, D11.1, D12.1, EFD_C1.2, EFD_C2.2, EFD_C5.2, EFD_C6.2, EFD_C7.2, EPD_C8.2, EPD_C9.2, EPD_C10.2, EPD_C11.2, EPD_C12.2, IC1.3 (GND), IC4.2 (VSS), J1.8, J1.17, J1.MP1, J1.MP2, J2.A1, J2.A12, J2.B1, J2.B12, J2.MP1, J2.MP2, J2.MP3, J2.MP4, J3.4, J4.G1 (GND_1), J4.G2 (GND_2), J4.G3 (GND_3), J4.G4 (GND_4), J4.P6 (VSS), MCP73831.2 (VSS), R1_PWRUSB1.1, R2.1, R2-USB.2, R2-USB1.1, R2_BAT.1, R4.1, RESET_BUTTON.1, RESET_BUTTON.2, SENSOR2.1 (GND), SENSOR2.5 (SDO), SENSOR2.7 (GND), SJ1.1, TANT.-, TP4.TP, TP5.TP, U1.4 (GND), U1.9 (EXP), U2.1 (GND), U2.28 (GND), U2.29_1 (GND), U2.29_2 (GND), U2.29_3 (GND), U2.29_4 (GND), U2.29_5 (GND), U2.29_6 (GND), U2.29_7 (GND), U2.29_8 (GND), U2.29_9 (GND), U3.13 (GND), U4.1 (CTG), U4.4 (GND), U4.6 (QSTRT), U4.9 (EP)
GPIO8: R1.1, U2.10 (IO8)
I2C_PW: C1.1, C2.1, R1_PINH.2, R2_PINH.2, SENSOR2.2 (CSB), SENSOR2.6 (VDDIO), SENSOR2.8 (VDD), U2.17 (IO19)
INT_RTC: R1_PINH1.1, TP15.TP, U2.8 (IO0), U3.3 (SQW/!INT)
IO/BOOT: BOOT_BUTTON.3, BOOT_BUTTON.4, C6.1, R_BOOT.1, U2.15 (IO9)
IO/CHANGE: C10.1, CHANGE_BUTTON.3, CHANGE_BUTTON.4, R_CHANGE.1, U2.23 (IO15)
MISO: D12.2, J4.P7 (DAT0), R8.1, TP6.TP, U1.2 (DO(IO1)), U2.27 (IO2)
MOSI: D11.2, J1.14, J4.P3 (CMD), R7.1, TP7.TP, U1.5 (DI(IO0)), U2.7 (IO7)
unnamed: J2.B5, R2-USB.1
unnamed: C1_BAT1.1, D2.1 (CATHODE), IC4.1 (VIN), IC4.3 (CE), Q1.2 (S)
unnamed: MCP73831.1 (STAT), R1_BAT.2
unnamed: CHG_LED.C, R1_BAT.1
unnamed: MCP73831.5 (PROG), R2_BAT.2
unnamed: C_DELAY.1, IC1.5 (CT)
unnamed: C4.1, D3.2 (A), D4.1 (K)
unnamed: J2.A5, R2-USB1.2
unnamed: D7.1 (CATHODE), R_CAPACITOR.1
unnamed: EFD_C2.1, J1.5
unnamed: EFD_C1.1, J1.4
unnamed: EPD_C12.1, J1.24
unnamed: EPD_C10.1, J1.22
unnamed: EPD_C8.1, J1.20
unnamed: EFD_C7.1, J1.19
unnamed: EFD_C6.1, J1.18
PREVGH: D5.1 (K), EPD_C9.1, J1.21
PREVGL: D4.2 (A), EPD_C11.1, J1.23
RESE: J1.3, Q3.2 (S), R3.2
RESE': R2.2, R3.1, SJ1.2
RESET: C5.1, IC1.1 (VOUT), RESET_BUTTON.3, RESET_BUTTON.4, R_RESET.1, U2.3 (EN)
RTC_RST: U2.16 (IO18), U3.4 (!RST)
RX: TP2.TP, U2.24 (RXD0/GPIO17)
SCK: D10.2, J1.13, J4.P5 (CLK), R6.1, TP8.TP, U1.6 (CLK), U2.6 (IO6)
SCL: J3.1, R2_PINH.1, SENSOR2.4 (SCK), U2.20 (IO22), U3.16 (SCL), U4.7 (SCL)
SDA: J3.2, R1_PINH.1, SENSOR2.3 (SDI), U2.19 (IO21), U3.15 (SDA), U4.8 (SDA)
SRC: C4.2, D5.2 (A), L1.1, Q3.3 (D)
SS_SD: D8.2, J4.P2 (CD/DAT3), R10.1, U2.4 (IO4)
TX: TP1.TP, U2.25 (TXD0/GPIO16)
USB_D+: D1.4 (I/O2_2), U2.14 (IO13)
USB_D-: D1.6 (I/O1_2), U2.13 (IO12)
VBAT: C2_BAT.1, MCP73831.3 (VBAT), Q1.3 (D), TP3.TP, U4.2 (CELL), U4.3 (VDD)
VBUS: C1_BAT.1, C4_USB.1, C4_USB1.1, CHG_LED.A, D1.2 (GND), D2.2 (ANODE), MCP73831.4 (VIN), PFMF.050.1.2, Q1.1 (G), R1_PWRUSB1.2, TP14.TP
VRTC: C8.1, C10_SUPERCAP.2, R_CAPACITOR.2, U3.14 (VBAT)
VUSB: J2.A4, J2.A9, J2.B4, J2.B9, PFMF.050.1.1

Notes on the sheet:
USB C connector & ESD protection
LDO Voltage Regulator
Display Type Selector
E-Paper Drive Circuit
Li-Po Battery Charging Controller
E-Paper Display Header
EPD Power
Environmental Sensor BME688
ESP32 C6
Voltage Supervisor + Reset & Boot / IO Button
Battery Charge Level
RTC Module DS3231SN
Test Pads
Qwiic / Stemma QT
SPI ESD Protection Lines
External NOR Flash 64MB

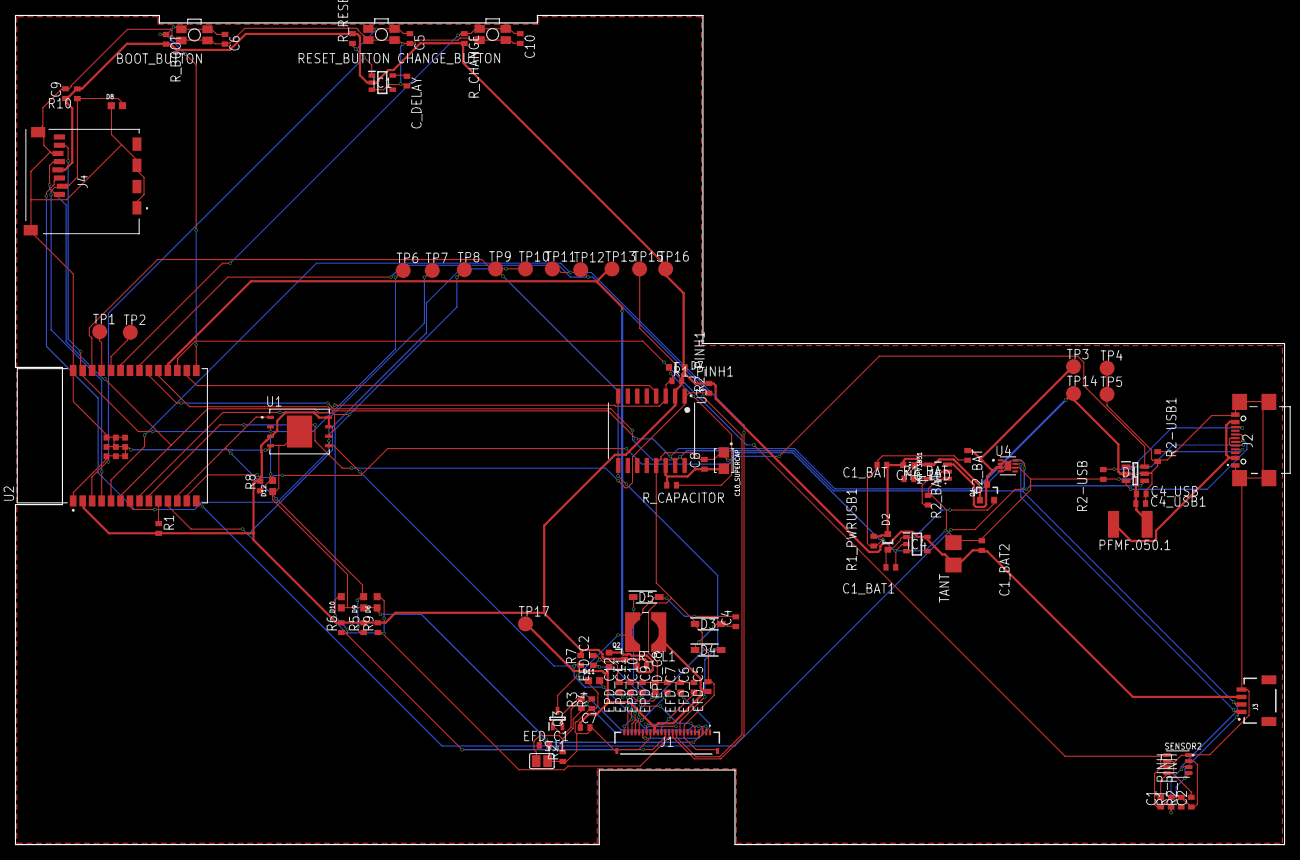
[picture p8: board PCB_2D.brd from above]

Board: 2 copper layers, 170.2 x 111.2 mm, 103 parts (0 on the bottom side), 55 nets.

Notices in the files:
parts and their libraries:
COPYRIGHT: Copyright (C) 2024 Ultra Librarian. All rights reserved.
